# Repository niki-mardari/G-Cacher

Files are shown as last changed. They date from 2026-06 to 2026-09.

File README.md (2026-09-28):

# G-Cacher

**A portable GNSS surveying and location-mapping tool**

<p align="center">
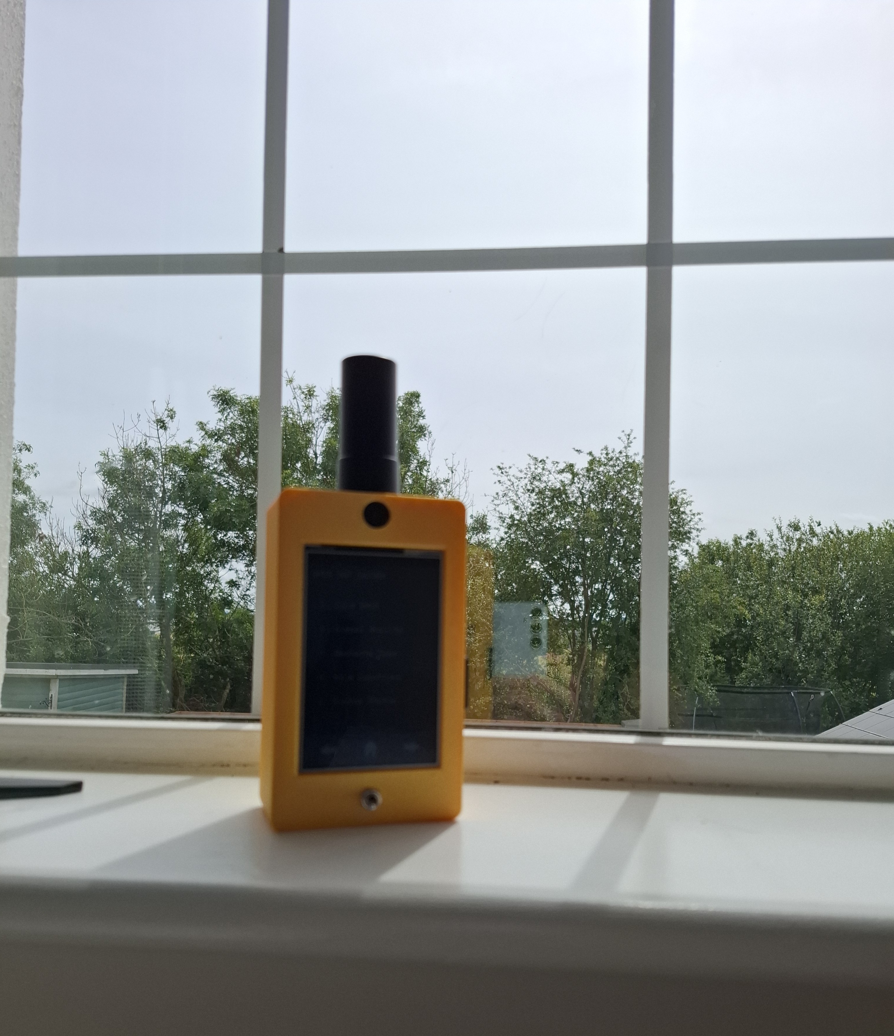
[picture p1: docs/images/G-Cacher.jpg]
G-Cacher physical device
  
</p>

<p align="center">
  
  
  
  
  
</p>

---

## Overview

G-Cacher is a student engineering project developed during the BIP26 programme. The project utilizes a portable GNSS device. A web platform for collecting, storing, and visualising location data.

---

## What it currently does:

Device:

* Reads live GNSS data from multiple satellite constellations
* Displays position, altitude, speed, satellite count, HDOP, and signal quality
* Logs selected GNSS data to an SD card
* Sends telemetry to a backend server

Webserver (Frontend/ Backend):

* Visualises recorded location points in a web dashboard on a map
* A GeoCache-style navigation game
* Display recorded latitude, longitude, and altitude points in 3D
* Saves and displays saved locations

---

## Device Interface

The device uses a touch-based menu system for viewing live data and interacting with the project features.

The main device menus include:

* Live GNSS — displays parsed position, altitude, speed, HDOP, satellite count, date, and time.
* Signal Quality — shows whether the current GNSS signal is good, usable, weak, or unavailable.
* NMEA / Logging — supports viewing GNSS data and saving records to SD card.
* Saved Location — records a location and sends it to the backend as a saved asset.
* System Status — shows device, sensor, SD card, and telemetry status.

<p align="center">
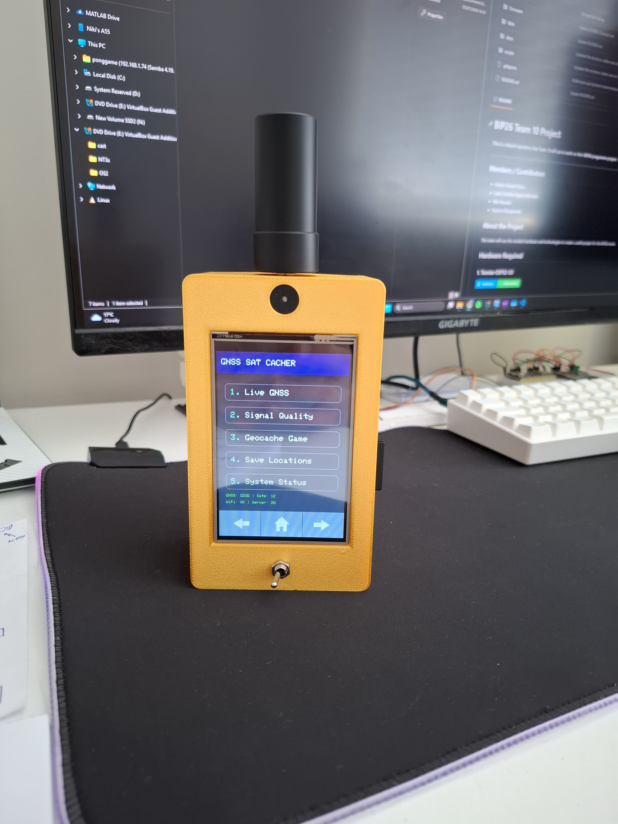
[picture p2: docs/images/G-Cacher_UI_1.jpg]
G-Cacher Interface
  
</p>

---

## Web Platform

The web platform receives telemetry from the G-Cacher device and provides a simple interface for interacting with the collected location data.

It includes a frontend website and a FastAPI backend. The backend receives device telemetry, stores records, and provides endpoints for the frontend. The frontend allows users to view location data, play the GeoCache game, inspect saved assets, and visualise terrain points. Deploy easily with Docker.

<p align="center">
  <strong>SatCacher Home Page</strong><br>
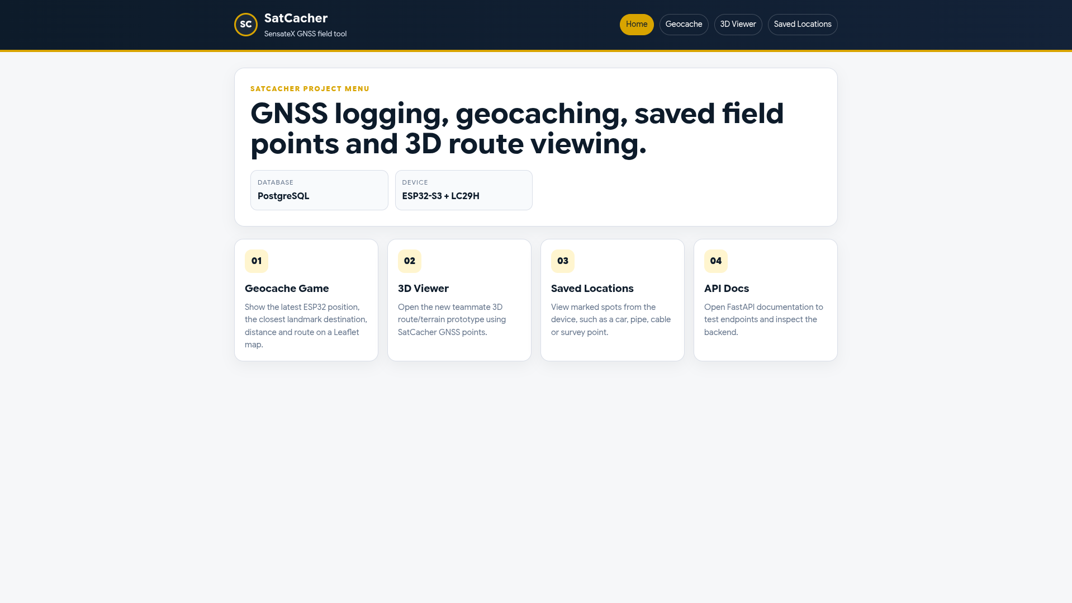
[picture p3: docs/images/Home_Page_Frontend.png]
SatCacher home page
  
</p>

---

## GeoCache Game

The GeoCache Game is a location-based feature designed for tourists or first-time visitors exploring Ireland.

The backend stores predefined landmarks. The G-Cacher device sends the user’s current location to the server, and the web platform calculates whether the user is getting closer to or further away from the target.

The device can then give simple direction feedback:

* **Red** — getting closer
* **Blue** — moving further away
* **Yellow** — not enough movement detected yet

<p align="center">
  <strong>GeoCache Game</strong><br>
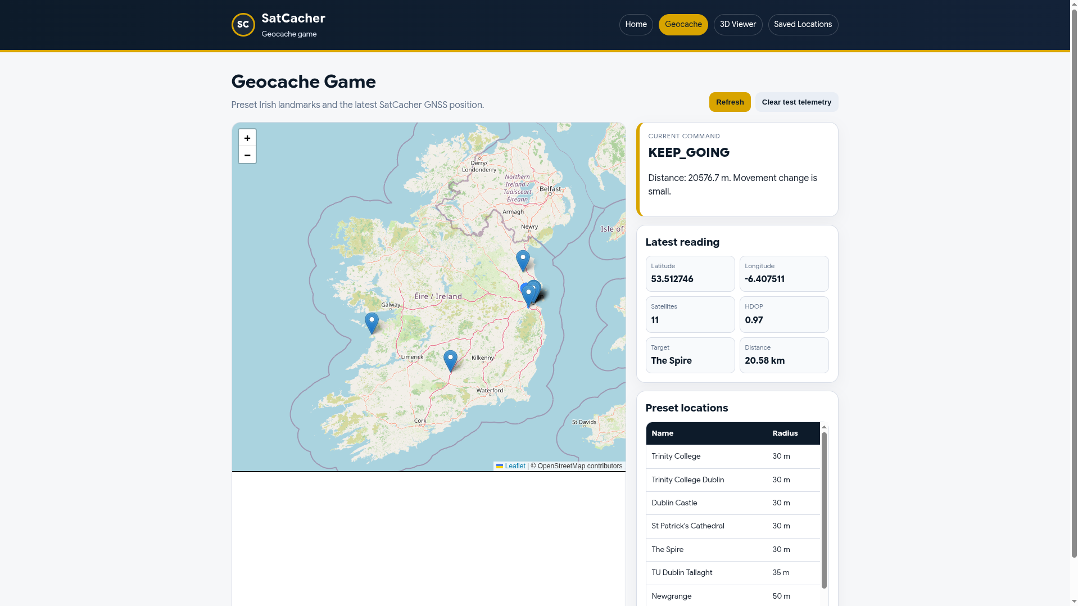
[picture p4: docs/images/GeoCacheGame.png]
GeoCache game
  
</p>

<p align="center">
  <strong>Sample Waypoint</strong><br>
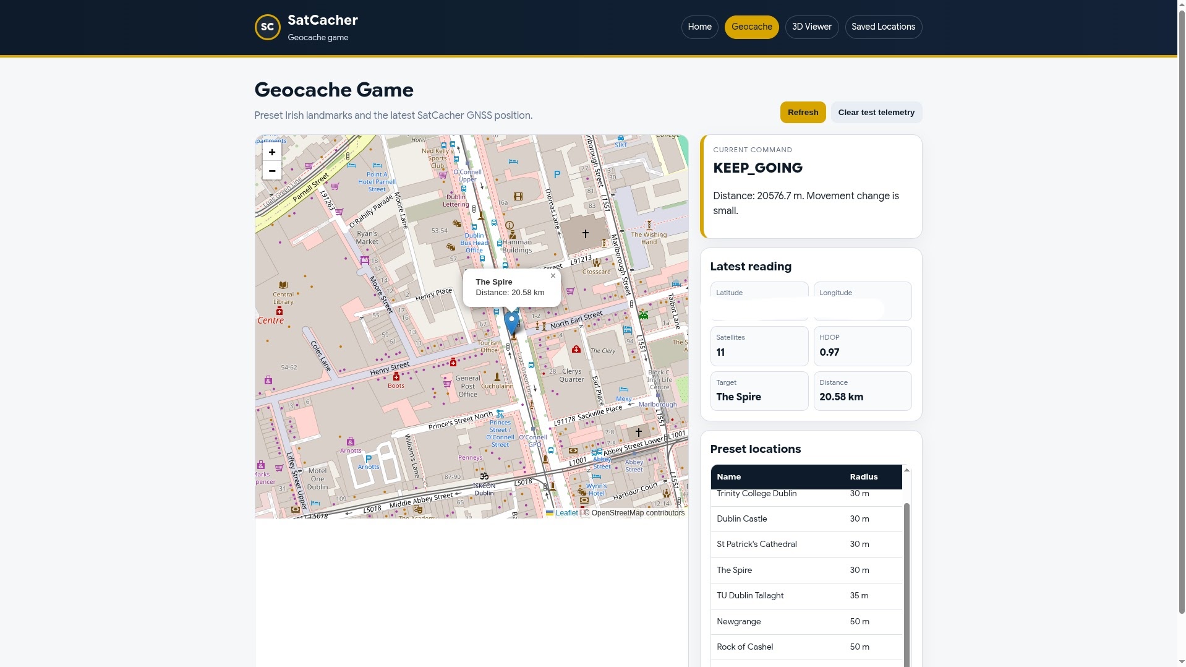
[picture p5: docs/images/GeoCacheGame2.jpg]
Sample waypoint
  
</p>

---

## 3D Terrain Viewer

The 3D Terrain Viewer displays recorded or simulated GNSS points using latitude, longitude, and altitude.

It can be used to visualise walking routes, field test data, campus areas, and rough terrain-like surfaces. Points can come from the FastAPI database, imported JSON files, or simulated data.

<p align="center">
  <strong>Ideal Sample Terrain 1</strong><br>
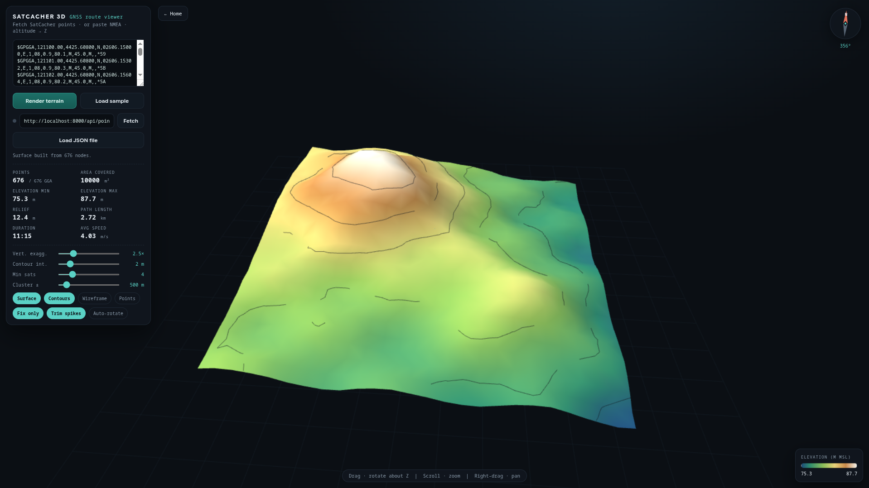
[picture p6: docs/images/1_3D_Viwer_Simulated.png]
3D terrain viewer
  
</p>

<p align="center">
  <strong>Ideal Sample Terrain 2</strong><br>
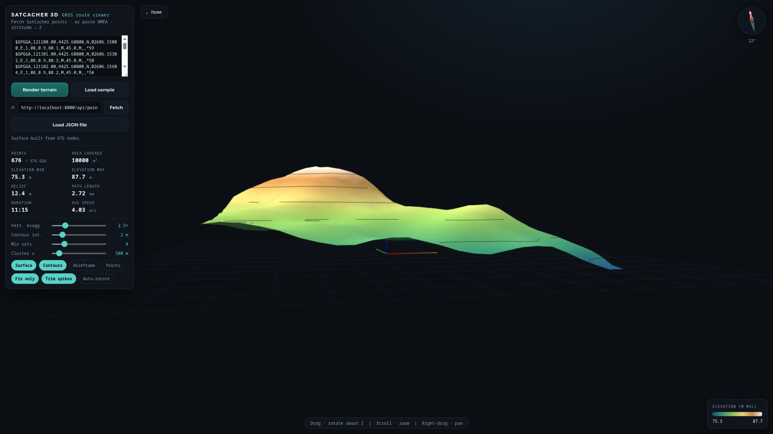
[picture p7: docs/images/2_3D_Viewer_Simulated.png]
Sample terrain
  
</p>

<p align="center">
  <strong>TUD Tallaght Campus Terrain</strong><br>
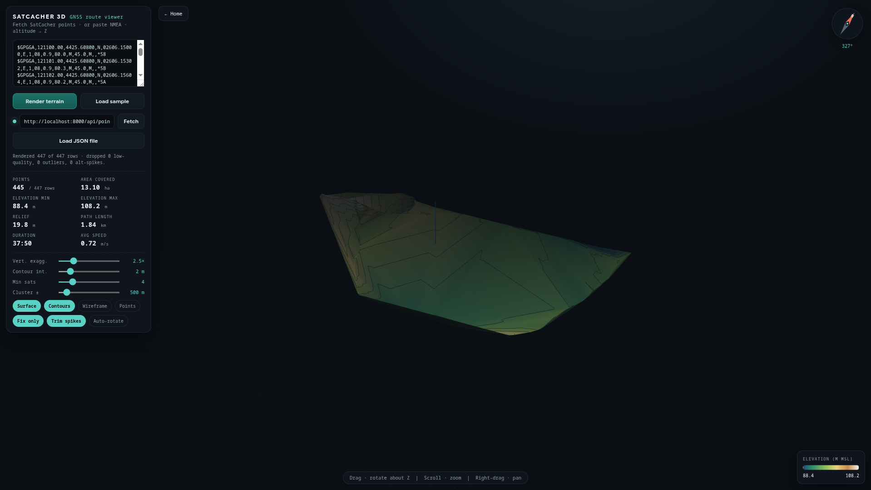
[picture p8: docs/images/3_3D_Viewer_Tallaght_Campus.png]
TUD Tallaght campus terrain
  
</p>

---

## Saved Locations

The Saved Locations feature allows the device to record an important location and send it to the backend as an asset.

On the web dashboard, saved points can be viewed on a map and given extra details such as a name, category, and description. This can be used for marking parked cars, survey points, field markers, underground pipes, cables, or other important positions that may need to be found again later.

<p align="center">
  <strong>Saved Locations</strong><br>
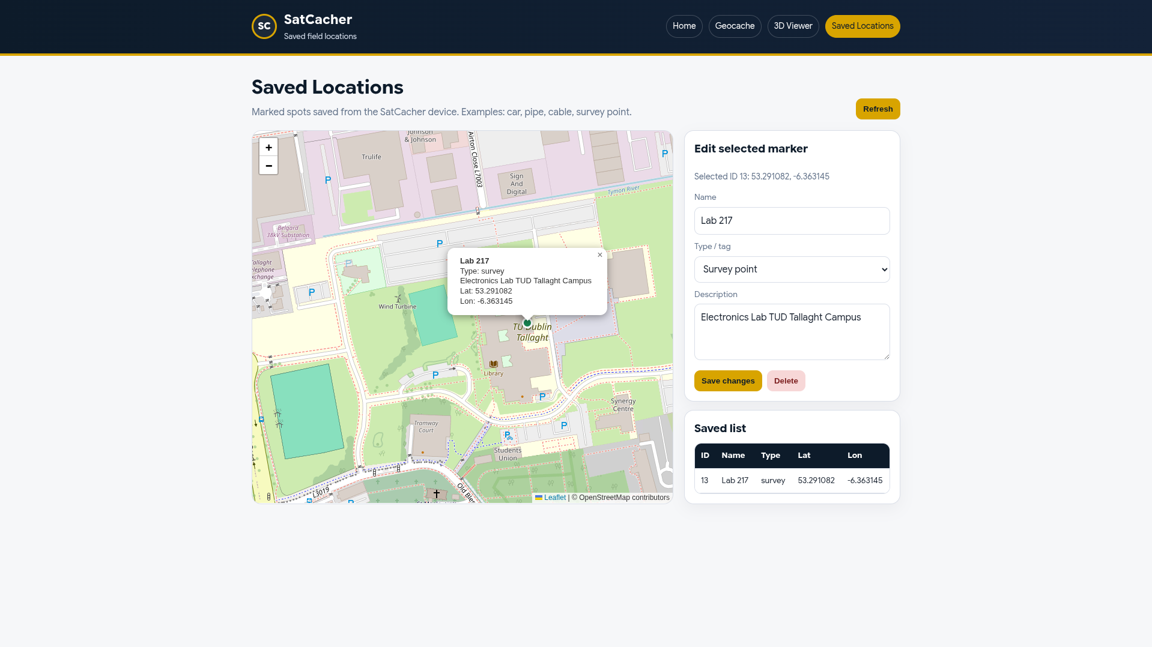
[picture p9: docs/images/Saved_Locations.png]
Saved locations page
  
</p>

---

---

## Hardware

### Tenstar ESP32-S3




### LC29H(AA) GNSS Receiver




### ILI9488 4.0 Inch



---

## Learning Portal / Wiki



The wiki contains the more detailed technical documentation for GNSS, NMEA, sensors, wiring, software setup, and project development.



---

## Future Improvements

Future improvements may include:

* Further documentation
* Sensor Fusion with extended Kalman filtering
* PCB (Work in progress)
* Improved enclosure

---

## Contributors

* Andrei-Eduard Rusu
* Carla Daniela Zegarra Bernabe
* Niki Mardari
* Szymon Blazejowski

---
---

## Notes

Contributions, suggestions, and improvements are welcome.

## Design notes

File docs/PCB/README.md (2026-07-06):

# This is the first iteration of the PCB implementation. Currently it's undergoing work. If are able to contribute to this, that would preogress the development much faster.

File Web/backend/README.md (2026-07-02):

# SatCacher Backend

FastAPI backend for the SatCacher project.

The ESP32 posts telemetry to `/api/telemetry`.
The backend stores it in PostgreSQL and checks the nearest preset landmark.

The saved location feature uses `/api/assets`.
This is useful for marked spots like a parked car, pipe, cable, valve, or survey point.

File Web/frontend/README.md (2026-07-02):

# SatCacher Frontend

The frontend is kept simple on purpose.

## Main files

- `index.html` - simple home menu
- `geocache.html` - geocache game map
- `saved-locations.html` - saved location markers and editing
- `terrain.html` - new 3D viewer prototype
- `prototypes/terrain-original.html` - old terrain page kept as backup
- `prototypes/3D_Modelling_Test_Sample.html` - teammate prototype copy

## JavaScript

- `js/config.js` - chooses the backend URL based on the current browser host
- `js/geocache.js` - loads latest telemetry and landmarks
- `js/saved-locations.js` - loads and edits saved field locations

The pages use Leaflet from a CDN for maps.

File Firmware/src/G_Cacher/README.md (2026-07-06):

# GNSS Sat Cacher Firmware so far

Clean modular Arduino firmware for the Tenstar ESP32-S3 GNSS G Cacher project

## Files

```text
GNSS_Sat_Cacher_Clean/
├── GNSS_Sat_Cacher_Clean.ino
└── src/
    ├── AppState.h
    ├── Buzzer.h / Buzzer.cpp
    ├── Config.h
    ├── GnssManager.h / GnssManager.cpp
    ├── Hardware.h / Hardware.cpp
    ├── InputManager.h / InputManager.cpp
    ├── NetworkManager.h / NetworkManager.cpp
    ├── SensorManager.h / SensorManager.cpp
    ├── StorageManager.h / StorageManager.cpp
    ├── UiManager.h / UiManager.cpp
    └── Utils.h / Utils.cpp
```

## Where to edit settings

Open `src/Config.h` and fill in only your local private values:

```cpp
const char *const WIFI_SSID = "";
const char *const WIFI_PASSWORD = "";
const char *const SERVER_HOST = "";
const char *const TELEMETRY_URL = "";
const char *const ASSETS_URL = "";
```

## Required libraries

- LovyanGFX
- TinyGPSPlus
- Adafruit BMP280
- ArduinoJson
- QMI8658C `ImuDrv.hpp` driver used by accelerometer can be found here: 
  [lewisxhe LIB](https://github.com/lewisxhe/SensorLib/tree/master/src).

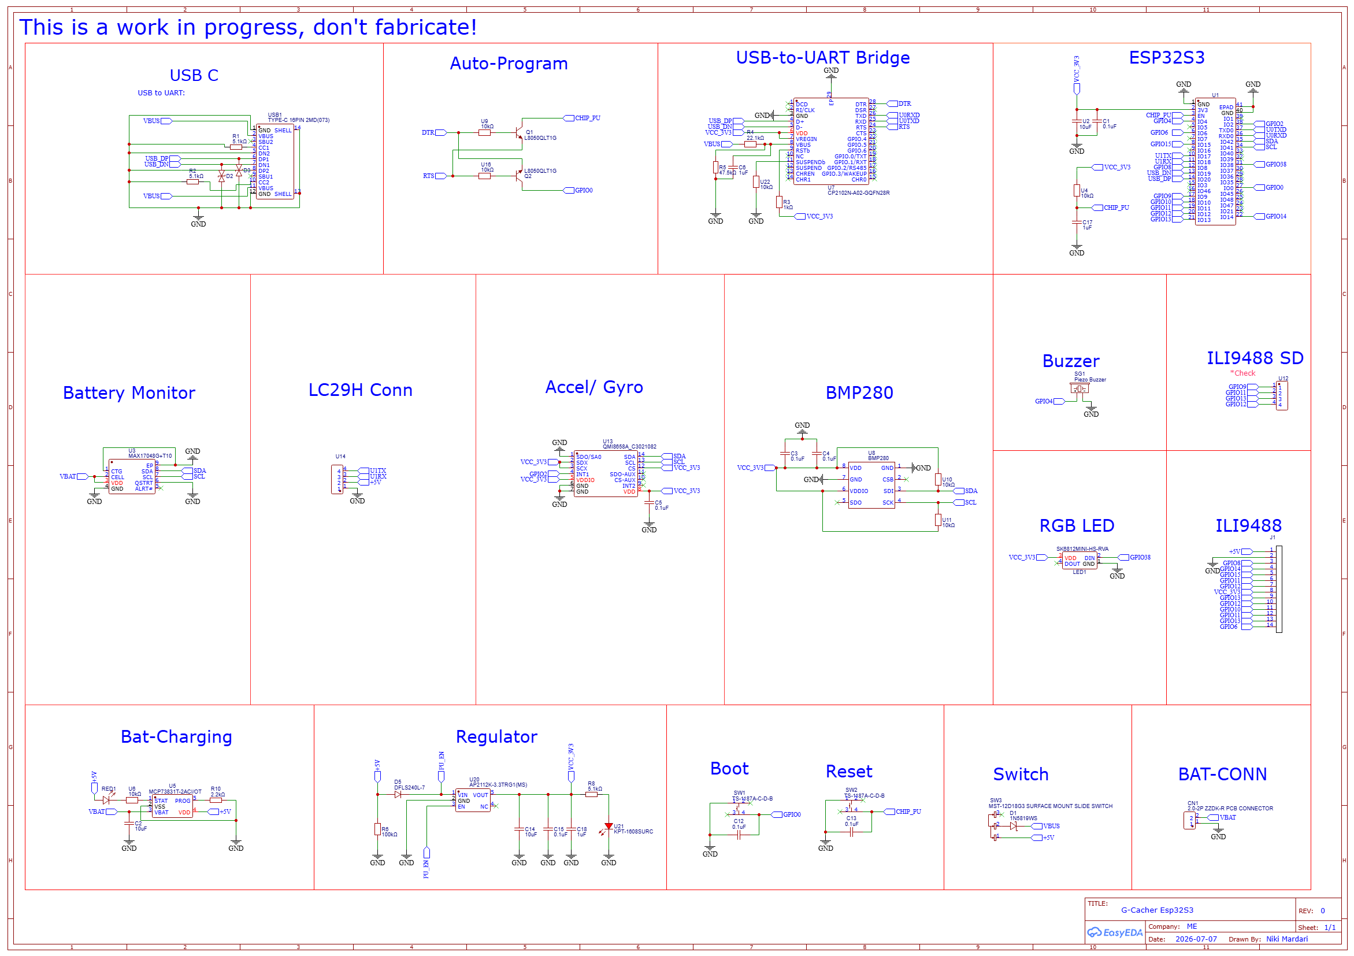
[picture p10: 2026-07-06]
docs/PCB/Schematic_G-Cacher_2026-07-06.png

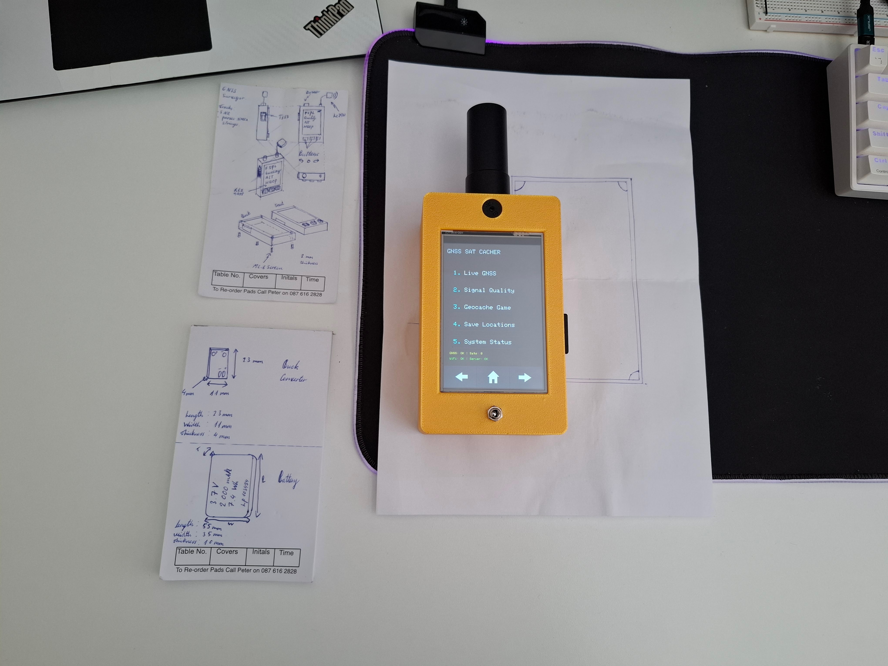
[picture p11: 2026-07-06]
docs/images/Prototype.jpg

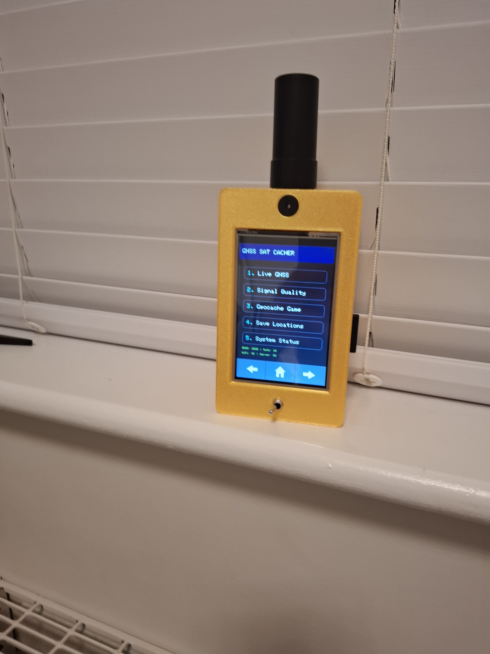
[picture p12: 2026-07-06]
docs/images/G-Cacher_UI_2.jpg

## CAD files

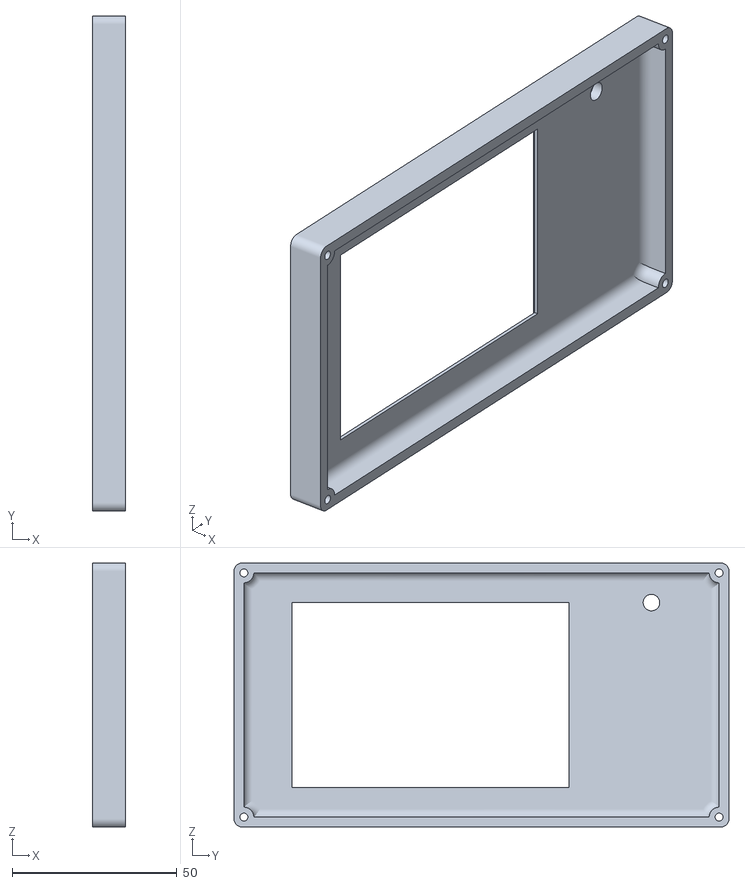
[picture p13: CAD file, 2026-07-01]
3D_Models/Final/Part Studio 2 - Part 1.stl
10.0 x 150.0 x 80.0

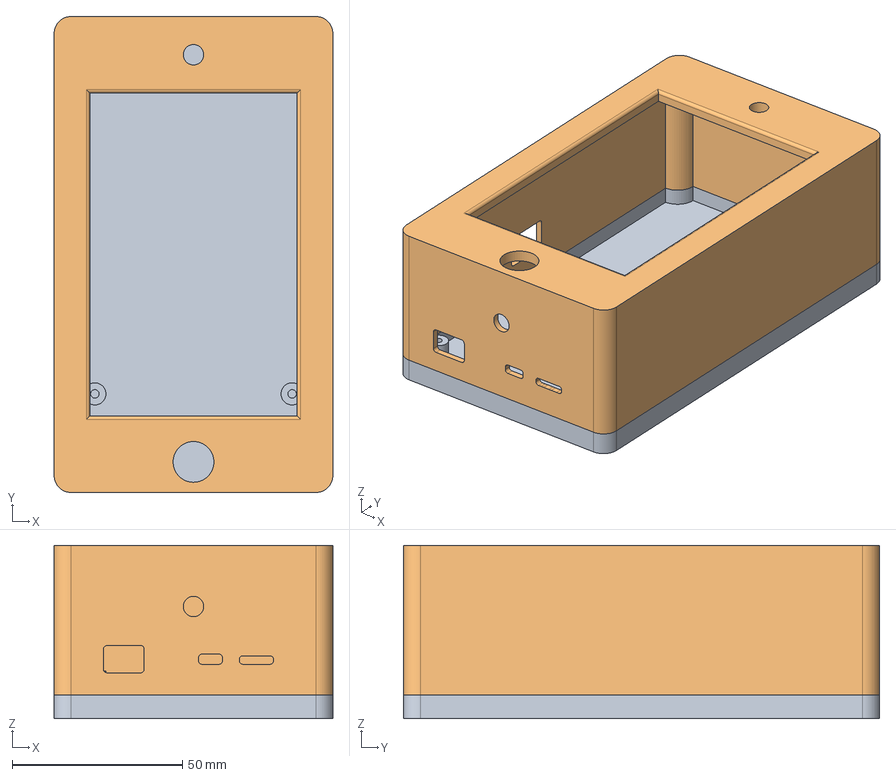
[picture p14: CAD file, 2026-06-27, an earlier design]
3D_Models/Rev0/GNSS_BOX.step
82.0 x 140.0 x 51.0 mm

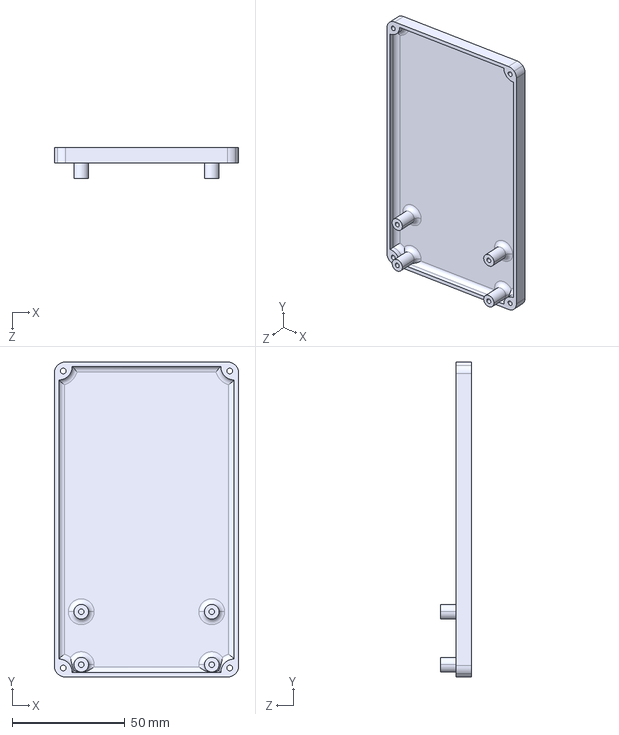
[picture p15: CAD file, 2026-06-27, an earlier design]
3D_Models/Rev1/Bottom[1].STEP
82.0 x 140.0 x 14.0 mm

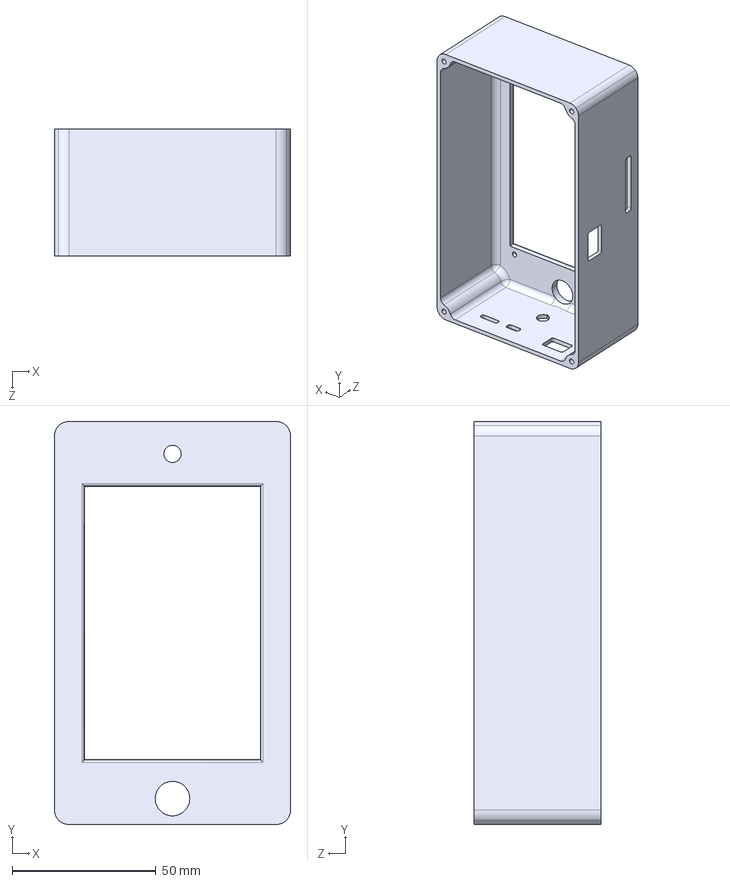
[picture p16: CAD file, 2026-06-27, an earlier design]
3D_Models/Rev1/Top[1].STEP
82.0 x 140.0 x 44.0 mm

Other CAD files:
3D_Models/Rev0/GNSS_BOX.f3d
3D_Models/Rev1/Bottom[1].SLDPRT
3D_Models/Rev1/Top[1].SLDPRT
3D_Models/Rev2/Bottom[1].f3d
3D_Models/Rev2/Top[1].f3d

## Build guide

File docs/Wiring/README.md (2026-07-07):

# This is the current wiring used for the test hardware

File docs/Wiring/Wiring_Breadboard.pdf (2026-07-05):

Wiring:

ESP32-S3 Tenstar Pin | ST7796S / ILI9488 Display Pin | Touch Pin | SD Card Pin | Buzzer
5V / VBUS | VCC | VCC if required | VCC if required | -
3.3V | LED / BL | VCC if touch is 3.3V only | VCC if SD module is 3.3V only | -
GND | GND | GND | GND | Buzzer -
GPIO8 (A5) | CS | - | - | -
GPIO14 (A4) | RESET / RST | - | - | -
GPIO15 (A3) | DC / RS | - | - | -
GPIO11 (D11 / MOSI) | SDI / MOSI | T_DIN | - | -
GPIO12 (D12 / SCK) | SCK / CLK | T_CLK | - | -
GPIO13 (D13 / MISO) | SDO / MISO if used | T_DO | - | -
GPIO10 (D10) | - | T_CS | - | -
GPIO6 (D6) | - | T_IRQ | - | -
GPIO9 (D9) | - | - | SD_CS | -
GPIO5(D5) | - | - | - | Buzzer +
GPIO35(MOSI) | - | - | SD_MOSI | -
GPIO36(SCK) | - | - | SD_SCK | -
GPIO37(MISO) | - | - | SD_MISO | -
ESP32-S3 Tenstar Pin | LC29H Pin
GPIO17 (A1 / ESP32 RX) | Pin 8 Pi TXD0 / LC29H TX
GPIO18 (A0 / ESP32 TX) | Pin 10 Pi RXD0 / LC29H RX
GND | Pin 6 GND
Not connected | LC29H VCC if LC29H is powered by USB
Power bank USB output | LC29H USB power

Note: The RX and TX pins may need to be swapped on LC29H, some boards mislabel them

Internal ESP32-S3 GPIO | Internal Device Pin
GPIO7 | Onboard ST7789 CS
GPIO39 | Onboard ST7789 DC
GPIO40 | Onboard ST7789 RESET
GPIO45 | Onboard ST7789 Backlight
GPIO35 | Onboard ST7789 MOSI
GPIO36 | Onboard ST7789 SCK
GPIO37 | Onboard ST7789 MISO
SPI Function | ESP32-S3 Tenstar Pin | Shared By
MOSI | GPIO11 (D11 / MOSI) | Display, Touch, SD Card
SCK | GPIO12 (D12 / SCK) | Display, Touch, SD Card
MISO | GPIO13 (D13 / MISO) | Touch, SD Card
Display CS | GPIO8 (A5) | Display only
Touch CS | GPIO10 (D10) | Touch only
SD CS | GPIO9 (D9) | SD Card only

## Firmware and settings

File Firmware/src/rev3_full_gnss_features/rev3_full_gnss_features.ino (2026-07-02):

/********************************************************
  GNSS Sat Cacher Rev2 Clean UI
  Tenstar ESP32-S3 + LC29H GNSS + ILI9488/XPT2046 + SD + Backend

  Last updated: 2026-07-01

  What this firmware does:
  - Reads live GNSS data from the LC29H using TinyGPSPlus
  - Shows a simple touch menu called GNSS Sat Cacher
  - Shows Live GNSS, Signal Quality, Geocache, Save Locations, and System Status screens
  - Shows a compact FSPL table inside Signal Quality
  - Logs GNSS/sensor/server data to the SD card
  - Uploads telemetry to the FastAPI backend
  - Receives the current geocache command/message from the backend
  - Lets the user save the current location from the Save Locations menu using /api/assets

  Main anti-flicker design:
  - Full screen redraw only happens when changing menu
  - Live values update only inside small cleared rectangles
  - Display updates run every DISPLAY_UPDATE_MS, not continuously

  Required libraries:
  - LovyanGFX
  - TinyGPSPlus
  - Adafruit BMP280
  - ArduinoJson
  - ImuDrv.hpp for the QMI8658C
********************************************************/

#define LGFX_USE_V1

#include <Arduino.h>
#include <Wire.h>
#include <SPI.h>
#include <FS.h>
#include <SD.h>
#include <math.h>
#include <string.h>

#include <WiFi.h>
#include <HTTPClient.h>
#include <ArduinoJson.h>

#include <LovyanGFX.hpp>
#include <TinyGPSPlus.h>
#include <Adafruit_BMP280.h>

#include "ImuDrv.hpp"

// ------------------------------------------------------------
// User settings
// ------------------------------------------------------------

const char *WIFI_SSID = "yep";
const char *WIFI_PASSWORD = "12345678";

// Change this when the backend runs on another laptop.
const char *SERVER_HOST = "10.107.7.42";
const char *TELEMETRY_URL = "http://10.107.7.42:8000/api/telemetry";
const char *ASSETS_URL    = "http://10.107.7.42:8000/api/assets";

const char *DEVICE_ID = "tenstar_001";

// ------------------------------------------------------------
// I2C sensors
// ------------------------------------------------------------

#define I2C_SDA 42
#define I2C_SCL 41

#define BMP_ADDR_1 0x77
#define BMP_ADDR_2 0x76

#define QMI_ADDR_1 0x6B
#define QMI_ADDR_2 0x6A

// ------------------------------------------------------------
// LC29H GNSS UART
// ------------------------------------------------------------

#define GNSS_RX_PIN 17
#define GNSS_TX_PIN 18
#define GNSS_BAUD   115200

// ------------------------------------------------------------
// TFT + touch SPI
// ------------------------------------------------------------

#define BIG_TFT_CS    8
#define BIG_TFT_RST   14
#define BIG_TFT_DC    15
#define BIG_TFT_MOSI  11
#define BIG_TFT_SCLK  12
#define BIG_TFT_MISO  13

#define TOUCH_CS      10
#define TOUCH_IRQ     -1

// ------------------------------------------------------------
// Dedicated SD SPI
// ------------------------------------------------------------

#define SD_CS    9
#define SD_SCLK  36
#define SD_MOSI  35
#define SD_MISO  37

#define SD_FREQ_SLOW 400000
#define SD_FREQ_MED  1000000
#define SD_FREQ_FAST 4000000

#define LOG_FILE "/sat_cacher_log.csv"
#define LOG_INTERVAL_MS 5000

// ------------------------------------------------------------
// Buzzer
// ------------------------------------------------------------

#define BUZZER_PIN 5
#define BUZZER_FREQ 1300
#define BUZZER_BEEP_MS 18

// ------------------------------------------------------------
// Display and touch
// ------------------------------------------------------------

#define BIG_W 320
#define BIG_H 480
#define DISPLAY_ROTATION 2

// Keep this slower to stop constant redrawing.
#define DISPLAY_UPDATE_MS 1500

// Web upload timing.
#define UPLOAD_INTERVAL_MS 5000
#define WIFI_RETRY_INTERVAL_MS 10000
#define HTTP_TIMEOUT_MS 2500

// Bottom nav bar.
#define NAV_Y 410
#define NAV_H 70
#define NAV_BACK_X0 0
#define NAV_BACK_X1 106
#define NAV_HOME_X0 107
#define NAV_HOME_X1 213
#define NAV_NEXT_X0 214
#define NAV_NEXT_X1 319

// Save button on Save Locations screen.
#define SAVE_BTN_X 18
#define SAVE_BTN_Y 330
#define SAVE_BTN_W 284
#define SAVE_BTN_H 46

#define BOOT_BUTTON_PIN 0
#define TOUCH_INVERT_X false

// ------------------------------------------------------------
// LovyanGFX class
// ------------------------------------------------------------

class LGFX_ILI9488_Touch : public lgfx::LGFX_Device
{
  lgfx::Panel_ILI9488 _panel;
  lgfx::Bus_SPI _bus;
  lgfx::Touch_XPT2046 _touch;

public:
  LGFX_ILI9488_Touch(void)
  {
    {
      auto cfg = _bus.config();
      cfg.spi_host = SPI3_HOST;
      cfg.spi_mode = 0;
      cfg.freq_write = 20000000;
      cfg.freq_read = 6000000;
      cfg.spi_3wire = false;
      cfg.use_lock = true;
      cfg.dma_channel = SPI_DMA_CH_AUTO;
      cfg.pin_sclk = BIG_TFT_SCLK;
      cfg.pin_mosi = BIG_TFT_MOSI;
      cfg.pin_miso = BIG_TFT_MISO;
      cfg.pin_dc   = BIG_TFT_DC;
      _bus.config(cfg);
      _panel.setBus(&_bus);
    }

    {
      auto cfg = _panel.config();
      cfg.pin_cs   = BIG_TFT_CS;
      cfg.pin_rst  = BIG_TFT_RST;
      cfg.pin_busy = -1;
      cfg.panel_width  = 320;
      cfg.panel_height = 480;
      cfg.memory_width  = 320;
      cfg.memory_height = 480;
      cfg.offset_x = 0;
      cfg.offset_y = 0;
      cfg.offset_rotation = 0;
      cfg.dummy_read_pixel = 8;
      cfg.dummy_read_bits = 1;
      cfg.readable = false;
      cfg.invert = false;
      cfg.rgb_order = false;
      cfg.dlen_16bit = false;
      cfg.bus_shared = true;
      _panel.config(cfg);
    }

    {
      auto cfg = _touch.config();
      cfg.spi_host = SPI3_HOST;
      cfg.freq = 1000000;
      cfg.pin_sclk = BIG_TFT_SCLK;
      cfg.pin_mosi = BIG_TFT_MOSI;
      cfg.pin_miso = BIG_TFT_MISO;
      cfg.pin_cs   = TOUCH_CS;
      cfg.pin_int  = TOUCH_IRQ;
      cfg.bus_shared = true;
      cfg.x_min = 200;
      cfg.x_max = 3900;
      cfg.y_min = 200;
      cfg.y_max = 3900;
      cfg.offset_rotation = 0;
      _touch.config(cfg);
      _panel.setTouch(&_touch);
    }

    setPanel(&_panel);
  }
};

// ------------------------------------------------------------
// Global objects
// ------------------------------------------------------------

LGFX_ILI9488_Touch tft;
SPIClass sdSPI(FSPI);

HardwareSerial GNSS(1);
TinyGPSPlus gps;

Adafruit_BMP280 bmp;
SensorQMI8658 qmi;
AccelerometerData acc;
GyroscopeData gyr;

// ------------------------------------------------------------
// State
// ------------------------------------------------------------

bool bmpOK = false;
bool qmiOK = false;
bool sdOK = false;
bool wifiOK = false;
bool serverOK = false;
bool touchOK = false;

char sdStatusText[20] = "NOT STARTED";
char wifiStatusText[20] = "OFFLINE";
char serverStatusText[24] = "NOT SENT";
char saveStatusText[42] = "No marked location saved yet";

float bmpTempC = 0.0f;
float bmpPressureHpa = 0.0f;
float accX = 0.0f;
float accY = 0.0f;
float accZ = 0.0f;
float accMagnitude = 0.0f;

uint32_t gnssChars = 0;
uint32_t lastGnssCharTime = 0;
char nmeaLine[150];
uint8_t nmeaIndex = 0;
char lastNmeaLine[150] = "No NMEA yet";

uint16_t rawTouchX = 0;
uint16_t rawTouchY = 0;
uint16_t touchX = 0;
uint16_t touchY = 0;
bool touchPressed = false;
bool touchWasDown = false;

unsigned long lastDisplayUpdate = 0;
unsigned long lastSensorUpdate = 0;
unsigned long lastLogTime = 0;
unsigned long lastUploadTime = 0;
unsigned long lastWiFiRetry = 0;
unsigned long lastTouchAction = 0;
unsigned long lastBootPress = 0;
unsigned long lastSerialPrint = 0;

uint32_t logRows = 0;
uint32_t uploadCount = 0;
uint32_t uploadFailCount = 0;
int lastHttpCode = 0;

char serverCommand[32] = "WAITING";
char serverColour[20] = "yellow";
char serverMessage[150] = "Waiting for telemetry upload";
char serverTarget[64] = "No target yet";
float serverDistanceM = -1.0f;

int lastSavedAssetId = -1;
bool lastSavedLocationValid = false;
double lastSavedLat = 0.0;
double lastSavedLon = 0.0;
double lastSavedAlt = 0.0;
int lastSavedSats = 0;
float lastSavedHdop = 0.0f;
char lastSavedName[64] = "No saved location";

// ------------------------------------------------------------
// Menu system
// ------------------------------------------------------------

enum MenuPage
{
  MENU_HOME = 0,
  MENU_LIVE_GNSS,
  MENU_SIGNAL_QUALITY,
  MENU_GEOCACHE,
  MENU_SAVE_LOCATIONS,
  MENU_SYSTEM,
  MENU_COUNT
};

MenuPage currentMenu = MENU_HOME;
bool forceRedraw = true;

// ------------------------------------------------------------
// Prototypes
// ------------------------------------------------------------

void initPins();
void initDisplay();
void initSensors();
void initGNSS();
void initSDCard();
bool tryStartSD(uint32_t frequency);
void createLogHeaderIfNeeded();
void appendLogRow();
void printFloatOrBlank(File &file, bool valid, double value, int decimals);

void updateGNSS();
void updateSensors();
void updateTouch();
void updateSDLogging();
void updateWiFiNonBlocking();
void updateWebUpload();

void uploadTelemetry();
void parseServerReply(const String &response);
void saveMarkedLocation();
void safeCopy(char *dest, size_t destSize, const char *src);

void handleSerialInput();
void handleBootButton();

bool readMappedTouch(uint16_t *xOut, uint16_t *yOut);
void processTouch(uint16_t x, uint16_t y);

void drawScreen();
void updateScreenValues();
void drawHeader(const char *title);
void drawNavBar();
void drawBackIcon(int cx, int cy, uint16_t colour);
void drawHomeIcon(int cx, int cy, uint16_t colour);
void drawNextIcon(int cx, int cy, uint16_t colour);
void drawLabelValue(int x, int y, const char *label, const char *value, uint16_t valueColour = TFT_WHITE);
void clearValueArea(int x, int y, int w = 185, int h = 24);

void drawHomeMenu();
void updateHomeValues();
void drawLiveGNSSMenu();
void updateLiveGNSSValues();
void drawSignalQualityMenu();
void updateSignalQualityValues();
void drawSystemMenu();
void updateSystemValues();
void drawGeocacheMenu();
void updateGeocacheValues();
void drawSaveLocationsMenu();
void updateSaveLocationsValues();

void nextMenu();
void previousMenu();
void goHome();

void beep();
void startupBeep();

bool gnssReceiving();
bool gnssHasFix();
int gnssSatellites();
float gnssHdop();
const char *qualityText();
const char *qualityReason();
uint16_t qualityColour();
uint16_t colourFromServer(const char *name);
const char *thermalStatus();
uint16_t thermalColour();
float calculateFSPL(float distanceKm, float frequencyMHz);
void printIPAddressToScreen(int x, int y);

// ------------------------------------------------------------
// Setup and loop
// ------------------------------------------------------------

void setup()
{
  Serial.begin(115200);
  delay(1000);

  Serial.println();
  Serial.println("====================================");
  Serial.println("GNSS Sat Cacher Rev2 Clean UI");
  Serial.println("====================================");
  Serial.println("LC29H TX -> GPIO17, LC29H RX -> GPIO18");
  Serial.println("SD: SCK36 MOSI35 MISO37 CS9");
  Serial.print("Telemetry URL: ");
  Serial.println(TELEMETRY_URL);

  initPins();
  startupBeep();

  Wire.begin(I2C_SDA, I2C_SCL);
  Wire.setClock(100000);

  initDisplay();
  initSensors();
  initGNSS();
  initSDCard();

  WiFi.mode(WIFI_STA);
  WiFi.begin(WIFI_SSID, WIFI_PASSWORD);
  safeCopy(wifiStatusText, sizeof(wifiStatusText), "CONNECTING");
  lastWiFiRetry = millis();

  drawScreen();

  Serial.println("Setup complete");
  Serial.println("Controls: n=next, p=previous, h=home, 1-5=menu, u=upload, m=save marked location");
}

void loop()
{
  handleSerialInput();
  handleBootButton();

  updateGNSS();
  updateTouch();
  updateSensors();
  updateWiFiNonBlocking();
  updateWebUpload();
  updateSDLogging();

  if (forceRedraw)
  {
    drawScreen();
    forceRedraw = false;
    lastDisplayUpdate = millis();
  }

  if (millis() - lastDisplayUpdate >= DISPLAY_UPDATE_MS)
  {
    lastDisplayUpdate = millis();
    updateScreenValues();
  }
}

// ------------------------------------------------------------
// Init
// ------------------------------------------------------------

void initPins()
{
  pinMode(BOOT_BUTTON_PIN, INPUT_PULLUP);
  pinMode(BUZZER_PIN, OUTPUT);
  digitalWrite(BUZZER_PIN, LOW);

  pinMode(BIG_TFT_CS, OUTPUT);
  pinMode(TOUCH_CS, OUTPUT);
  pinMode(SD_CS, OUTPUT);
  digitalWrite(BIG_TFT_CS, HIGH);
  digitalWrite(TOUCH_CS, HIGH);
  digitalWrite(SD_CS, HIGH);
}

void initDisplay()
{
  bool ok = tft.init();
  Serial.print("Display init: ");
  Serial.println(ok ? "OK" : "FAILED");

  tft.setRotation(DISPLAY_ROTATION);
  tft.fillScreen(TFT_BLACK);
  tft.setTextColor(TFT_WHITE, TFT_BLACK);
  tft.setTextSize(2);
  tft.setCursor(32, 210);
  tft.print("GNSS Sat Cacher");
  delay(500);
}

void initSensors()
{
  if (bmp.begin(BMP_ADDR_1))
  {
    bmpOK = true;
    Serial.println("BMP280 found at 0x77");
  }
  else if (bmp.begin(BMP_ADDR_2))
  {
    bmpOK = true;
    Serial.println("BMP280 found at 0x76");
  }
  else
  {
    bmpOK = false;
    Serial.println("BMP280 not found");
  }

  if (qmi.begin(Wire, QMI_ADDR_1, I2C_SDA, I2C_SCL))
  {
    qmiOK = true;
    Serial.println("QMI8658C found at 0x6B");
  }
  else if (qmi.begin(Wire, QMI_ADDR_2, I2C_SDA, I2C_SCL))
  {
    qmiOK = true;
    Serial.println("QMI8658C found at 0x6A");
  }
  else
  {
    qmiOK = false;
    Serial.println("QMI8658C not found");
    return;
  }

  qmi.configAccel(AccelFullScaleRange::FS_8G, 1000.0f, SensorQMI8658::LpfMode::MODE_0);
  qmi.configGyro(GyroFullScaleRange::FS_1000_DPS, 1000.0f, SensorQMI8658::LpfMode::MODE_0);
  qmi.enableAccel();
  qmi.enableGyro();
}

void initGNSS()
{
  GNSS.setRxBufferSize(2048);
  GNSS.begin(GNSS_BAUD, SERIAL_8N1, GNSS_RX_PIN, GNSS_TX_PIN);
  Serial.println("LC29H UART started");
}

void initSDCard()
{
  sdSPI.begin(SD_SCLK, SD_MISO, SD_MOSI, SD_CS);
  sdOK = tryStartSD(SD_FREQ_SLOW);
  if (!sdOK) sdOK = tryStartSD(SD_FREQ_MED);
  if (!sdOK) sdOK = tryStartSD(SD_FREQ_FAST);

  if (sdOK)
  {
    safeCopy(sdStatusText, sizeof(sdStatusText), "OK");
    createLogHeaderIfNeeded();
    Serial.println("SD card OK");
  }
  else
  {
    safeCopy(sdStatusText, sizeof(sdStatusText), "FAILED");
    Serial.println("SD card failed");
  }
}

bool tryStartSD(uint32_t frequency)
{
  digitalWrite(BIG_TFT_CS, HIGH);
  digitalWrite(TOUCH_CS, HIGH);
  digitalWrite(SD_CS, HIGH);
  SD.end();
  delay(80);
  bool ok = SD.begin(SD_CS, sdSPI, frequency, "/sd", 5);
  digitalWrite(SD_CS, HIGH);
  return ok;
}

// ------------------------------------------------------------
// Updates
// ------------------------------------------------------------

void updateGNSS()
{
  while (GNSS.available())
  {
    char c = GNSS.read();
    gps.encode(c);
    gnssChars++;
    lastGnssCharTime = millis();

    if (c == '\n')
    {
      nmeaLine[nmeaIndex] = '\0';
      if (nmeaIndex > 5)
      {
        strncpy(lastNmeaLine, nmeaLine, sizeof(lastNmeaLine) - 1);
        lastNmeaLine[sizeof(lastNmeaLine) - 1] = '\0';
      }
      nmeaIndex = 0;
    }
    else if (c != '\r')
    {
      if (nmeaIndex < sizeof(nmeaLine) - 1)
      {
        nmeaLine[nmeaIndex++] = c;
      }
      else
      {
        nmeaIndex = 0;
      }
    }
  }
}

void updateSensors()
{
  if (millis() - lastSensorUpdate < 150) return;
  lastSensorUpdate = millis();

  if (bmpOK)
  {
    bmpTempC = bmp.readTemperature();
    bmpPressureHpa = bmp.readPressure() / 100.0F;
  }

  if (qmiOK && qmi.isDataReady(static_cast<uint8_t>(ImuBase::DataReadyMask::ACCEL)))
  {
    qmi.readAccel(acc);
    qmi.readGyro(gyr);
    accX = acc.mps2.x;
    accY = acc.mps2.y;
    accZ = acc.mps2.z;
    accMagnitude = sqrt((accX * accX) + (accY * accY) + (accZ * accZ));
  }

  if (millis() - lastSerialPrint > 2500)
  {
    lastSerialPrint = millis();
    Serial.print("Menu "); Serial.print((int)currentMenu);
    Serial.print(" | Fix "); Serial.print(gnssHasFix() ? "YES" : "NO");
    Serial.print(" | Sats "); Serial.print(gnssSatellites());
    Serial.print(" | HDOP "); Serial.print(gnssHdop(), 2);
    Serial.print(" | WiFi "); Serial.print(wifiStatusText);
    Serial.print(" | Server "); Serial.print(serverStatusText);
    Serial.print(" | HTTP "); Serial.print(lastHttpCode);
    Serial.print(" | SD "); Serial.print(sdStatusText);
    Serial.println();
  }
}

void updateWiFiNonBlocking()
{
  if (WiFi.status() == WL_CONNECTED)
  {
    wifiOK = true;
    safeCopy(wifiStatusText, sizeof(wifiStatusText), "OK");
    return;
  }

  wifiOK = false;
  safeCopy(wifiStatusText, sizeof(wifiStatusText), "OFFLINE");

  if (millis() - lastWiFiRetry >= WIFI_RETRY_INTERVAL_MS)
  {
    lastWiFiRetry = millis();
    Serial.print("Retrying WiFi: ");
    Serial.println(WIFI_SSID);
    WiFi.disconnect(false);
    WiFi.begin(WIFI_SSID, WIFI_PASSWORD);
    safeCopy(wifiStatusText, sizeof(wifiStatusText), "CONNECTING");
  }
}

void updateWebUpload()
{
  if (millis() - lastUploadTime < UPLOAD_INTERVAL_MS) return;
  lastUploadTime = millis();

  if (WiFi.status() != WL_CONNECTED)
  {
    serverOK = false;
    safeCopy(serverStatusText, sizeof(serverStatusText), "NO WIFI");
    return;
  }

  uploadTelemetry();
}

void updateSDLogging()
{
  if (!sdOK) return;
  if (millis() - lastLogTime < LOG_INTERVAL_MS) return;
  lastLogTime = millis();
  appendLogRow();
}

void updateTouch()
{
  uint16_t x, y;
  bool pressed = readMappedTouch(&x, &y);
  touchPressed = pressed;

  if (!pressed)
  {
    touchWasDown = false;
    return;
  }

  touchOK = true;
  touchX = x;
  touchY = y;

  if (touchWasDown) return;
  touchWasDown = true;

  if (millis() - lastTouchAction < 220) return;
  lastTouchAction = millis();

  processTouch(x, y);
}

// ------------------------------------------------------------
// Wi-Fi / backend
// ------------------------------------------------------------

void uploadTelemetry()
{
  StaticJsonDocument<768> doc;
  doc["device_id"] = DEVICE_ID;
  doc["mode"] = "geocache";

  if (gps.location.isValid())
  {
    doc["lat"] = gps.location.lat();
    doc["lon"] = gps.location.lng();
  }
  if (gps.altitude.isValid()) doc["alt_m"] = gps.altitude.meters();
  if (gps.speed.isValid()) doc["speed_kmph"] = gps.speed.kmph();

  doc["satellites"] = gnssSatellites();
  if (gps.hdop.isValid()) doc["hdop"] = gps.hdop.hdop();
  doc["fix"] = gnssHasFix();

  if (bmpOK)
  {
    doc["temperature_c"] = bmpTempC;
    doc["pressure_hpa"] = bmpPressureHpa;
  }

  if (qmiOK)
  {
    doc["acc_x"] = accX;
    doc["acc_y"] = accY;
    doc["acc_z"] = accZ;
  }

  String body;
  serializeJson(doc, body);

  HTTPClient http;
  http.setTimeout(HTTP_TIMEOUT_MS);
  http.begin(TELEMETRY_URL);
  http.addHeader("Content-Type", "application/json");

  int code = http.POST(body);
  lastHttpCode = code;

  Serial.print("Telemetry HTTP: ");
  Serial.println(code);

  if (code >= 200 && code < 300)
  {
    String response = http.getString();
    serverOK = true;
    uploadCount++;
    safeCopy(serverStatusText, sizeof(serverStatusText), "OK");
    parseServerReply(response);
  }
  else
  {
    serverOK = false;
    uploadFailCount++;
    safeCopy(serverStatusText, sizeof(serverStatusText), "ERROR");
    if (code <= 0) Serial.println(http.errorToString(code));
  }

  http.end();
}

void parseServerReply(const String &response)
{
  StaticJsonDocument<1024> reply;
  DeserializationError err = deserializeJson(reply, response);
  if (err)
  {
    safeCopy(serverStatusText, sizeof(serverStatusText), "JSON ERR");
    Serial.print("Server JSON error: ");
    Serial.println(err.c_str());
    return;
  }

  safeCopy(serverCommand, sizeof(serverCommand), reply["command"] | "WAITING");
  safeCopy(serverColour, sizeof(serverColour), reply["screen_color"] | "yellow");
  safeCopy(serverMessage, sizeof(serverMessage), reply["message"] | "No message");
  const char *targetName = reply["target_name"] | nullptr;
  if (targetName == nullptr) targetName = reply["title"] | "No target";
  safeCopy(serverTarget, sizeof(serverTarget), targetName);
  serverDistanceM = reply["distance_m"] | -1.0f;

  bool doBeep = reply["beep"] | false;
  if (doBeep) beep();
}
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

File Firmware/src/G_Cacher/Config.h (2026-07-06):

#pragma once

#include <Arduino.h>

// ------------------------------------------------------------
// User settings
// ------------------------------------------------------------
// Keep private details out of the source file.
// Fill these in locally before flashing, or later replace this with SD/NVS settings.

const char *const WIFI_SSID = "";        // Put your Wi-Fi SSID here
const char *const WIFI_PASSWORD = "";    // Put your Wi-Fi password here

const char *const SERVER_HOST = "";      // Example: "192.168.1.50" or "my-server.local"
const char *const TELEMETRY_URL = "";    // Example: "http://192.168.1.50:8000/api/telemetry"
const char *const ASSETS_URL = "";       // Example: "http://192.168.1.50:8000/api/assets"

const char *const DEVICE_ID = "tenstar_001";

// ------------------------------------------------------------
// I2C sensors
// ------------------------------------------------------------

constexpr int I2C_SDA = 42;
constexpr int I2C_SCL = 41;

constexpr uint8_t BMP_ADDR_1 = 0x77;
constexpr uint8_t BMP_ADDR_2 = 0x76;

constexpr uint8_t QMI_ADDR_1 = 0x6B;
constexpr uint8_t QMI_ADDR_2 = 0x6A;

// ------------------------------------------------------------
// LC29H GNSS UART
// ------------------------------------------------------------
// Current sketch mapping kept from your uploaded firmware:
// LC29H TX -> ESP32 GPIO17, LC29H RX -> ESP32 GPIO18.

constexpr int GNSS_RX_PIN = 17;
constexpr int GNSS_TX_PIN = 18;
constexpr uint32_t GNSS_BAUD = 115200;

// ------------------------------------------------------------
// TFT + touch SPI
// ------------------------------------------------------------

constexpr int BIG_TFT_CS = 8;
constexpr int BIG_TFT_RST = 14;
constexpr int BIG_TFT_DC = 15;
constexpr int BIG_TFT_MOSI = 11;
constexpr int BIG_TFT_SCLK = 12;
constexpr int BIG_TFT_MISO = 13;

constexpr int TOUCH_CS = 10;
constexpr int TOUCH_IRQ = -1;

// ------------------------------------------------------------
// Dedicated SD SPI
// ------------------------------------------------------------

constexpr int SD_CS = 9;
constexpr int SD_SCLK = 36;
constexpr int SD_MOSI = 35;
constexpr int SD_MISO = 37;

constexpr uint32_t SD_FREQ_SLOW = 400000;
constexpr uint32_t SD_FREQ_MED = 1000000;
constexpr uint32_t SD_FREQ_FAST = 4000000;

const char *const LOG_FILE = "/sat_cacher_log.csv";
constexpr uint32_t LOG_INTERVAL_MS = 5000;

// ------------------------------------------------------------
// Buzzer
// ------------------------------------------------------------

constexpr int BUZZER_PIN = 5;
constexpr int BUZZER_CLICK_FREQ = 1300;
constexpr uint16_t BUZZER_CLICK_MS = 18;

// ------------------------------------------------------------
// Display and touch
// ------------------------------------------------------------

constexpr int BIG_W = 320;
constexpr int BIG_H = 480;
constexpr int DISPLAY_ROTATION = 2;

// UI refresh checks are cheap because fields only redraw when values change.
constexpr uint32_t DISPLAY_UPDATE_MS = 750;

constexpr int NAV_Y = 410;
constexpr int NAV_H = 70;
constexpr int NAV_BACK_X0 = 0;
constexpr int NAV_BACK_X1 = 106;
constexpr int NAV_HOME_X0 = 107;
constexpr int NAV_HOME_X1 = 213;
constexpr int NAV_NEXT_X0 = 214;
constexpr int NAV_NEXT_X1 = 319;

constexpr int SAVE_BTN_X = 18;
constexpr int SAVE_BTN_Y = 80;
constexpr int SAVE_BTN_W = 284;
constexpr int SAVE_BTN_H = 46;

constexpr int BOOT_BUTTON_PIN = 0;
constexpr bool TOUCH_INVERT_X = false;

// ------------------------------------------------------------
// Network timing
// ------------------------------------------------------------
// These values are intentionally slower than the original sketch so a bad Wi-Fi
// password or offline server does not constantly interrupt the touch UI.

constexpr uint32_t WIFI_RETRY_START_MS = 60000;    // 1 minute
constexpr uint32_t WIFI_RETRY_MAX_MS = 300000;     // 5 minutes

constexpr uint32_t UPLOAD_INTERVAL_MS = 15000;     // normal upload interval when healthy
constexpr uint32_t SERVER_RETRY_START_MS = 30000;  // 30 seconds after a server failure
constexpr uint32_t SERVER_RETRY_MAX_MS = 300000;   // 5 minutes

constexpr uint16_t HTTP_CONNECT_TIMEOUT_MS = 500;
constexpr uint16_t HTTP_READ_TIMEOUT_MS = 800;

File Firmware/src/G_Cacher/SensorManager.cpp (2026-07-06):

#include "SensorManager.h"
#include "Config.h"
#include "Hardware.h"
#include <Wire.h>
#include <math.h>

void initSensors(AppState &app)
{
  if (bmp.begin(BMP_ADDR_1))
  {
    app.bmpOK = true;
    Serial.println("BMP280 found at 0x77");
  }
  else if (bmp.begin(BMP_ADDR_2))
  {
    app.bmpOK = true;
    Serial.println("BMP280 found at 0x76");
  }
  else
  {
    app.bmpOK = false;
    Serial.println("BMP280 not found");
  }

  if (qmi.begin(Wire, QMI_ADDR_1, I2C_SDA, I2C_SCL))
  {
    app.qmiOK = true;
    Serial.println("QMI8658C found at 0x6B");
  }
  else if (qmi.begin(Wire, QMI_ADDR_2, I2C_SDA, I2C_SCL))
  {
    app.qmiOK = true;
    Serial.println("QMI8658C found at 0x6A");
  }
  else
  {
    app.qmiOK = false;
    Serial.println("QMI8658C not found");
    return;
  }

  qmi.configAccel(AccelFullScaleRange::FS_8G, 1000.0f, SensorQMI8658::LpfMode::MODE_0);
  qmi.configGyro(GyroFullScaleRange::FS_1000_DPS, 1000.0f, SensorQMI8658::LpfMode::MODE_0);
  qmi.enableAccel();
  qmi.enableGyro();
}

void updateSensors(AppState &app)
{
  if (millis() - app.lastSensorUpdate < 150) return;
  app.lastSensorUpdate = millis();

  if (app.bmpOK)
  {
    app.bmpTempC = bmp.readTemperature();
    app.bmpPressureHpa = bmp.readPressure() / 100.0f;
  }

  if (app.qmiOK && qmi.isDataReady(static_cast<uint8_t>(ImuBase::DataReadyMask::ACCEL)))
  {
    qmi.readAccel(acc);
    qmi.readGyro(gyr);
    app.accX = acc.mps2.x;
    app.accY = acc.mps2.y;
    app.accZ = acc.mps2.z;
    app.accMagnitude = sqrt((app.accX * app.accX) + (app.accY * app.accY) + (app.accZ * app.accZ));
  }
}

const char *thermalStatus(const AppState &app)
{
  if (!app.bmpOK) return "NO BMP";
  if (app.bmpTempC < 50.0f) return "OK";
  if (app.bmpTempC < 60.0f) return "WARM";
  return "HOT";
}

uint16_t thermalColour(const AppState &app)
{
  if (!app.bmpOK) return TFT_RED;
  if (app.bmpTempC < 50.0f) return TFT_GREEN;
  if (app.bmpTempC < 60.0f) return TFT_YELLOW;
  return TFT_RED;
}

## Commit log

2026-06-27 Added GNSS Box Rev1
    [GNSS_BOX.f3d]
2026-06-27 Box improvement
    Added Teardrop shape for vertical Hole in the top Part. Split the Top and bottom into 2 Parts. Added radii in the Top and Bottom Parts.
    [Bottom[1].SLDPRT, Bottom[1].STEP, Top[1].SLDPRT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]
2026-06-28 Device firmware so far, screen, sensors, menus, gnss parsing
    [Bottom[1].SLDPRT, Bottom[1].STEP, Bottom[1].f3d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]
2026-06-30 Added gnss api backend implementation for mcu
    [Bottom[1].SLDPRT, Bottom[1].STEP, Bottom[1].f3d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]
2026-06-30 Added Backend + Frontend + ESp32s3 integration
2026-06-30 Added Telemetry sending to server sketch for MCU device
2026-07-01 Revised the Casing
    [Part Studio 2 - Part 1.stl]
2026-07-01 Update Arduino GNSS backend sketch
2026-07-01 Removed old arduino messy code
2026-07-05 Wiring and rev0 schematic
    [G-Cacher-Schematic_2026-07-06.schdoc]
2026-07-06 Wiring & Schematic Rev0
    [G-Cacher-Schematic_2026-07-06.schdoc]
2026-07-06 Enhance README with image and device interface details
    Added image to README and updated device interface section.
2026-07-06 Updated examples and corrected schematic
    [GNSS_st7789.ino, esp32S3_Backend.ino, esp32S3_ILI9488.ino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]
2026-07-07 Wiring Readme
2026-07-08 Fixed Speed noise bouncing/ removed time in seconds
    [G_Cacher.ino]
2026-07-13 LED pin set to output
